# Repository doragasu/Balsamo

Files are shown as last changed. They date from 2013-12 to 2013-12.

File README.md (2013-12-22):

Balsamo
=======

A gadget (HW + SW) for unwanted calls filtering. The name comes from the Spanish acronym "Bloqueador Avanzado de Llamadas Sistemáticas, Automáticas, Molestas y Ocultas", that means something like "Advanced Blocker for Systematic, Automatic, Annoying and Hidden Calls". The acronym itself, means "Balm". When Balsamo detects an incoming call, it decodes the caller number. If the number is configured to be blocked (or if the number is hidden and hidden numbers are configured to be blocked), BALSAMO answers the call with a message pre-recorded inside a microSD card.

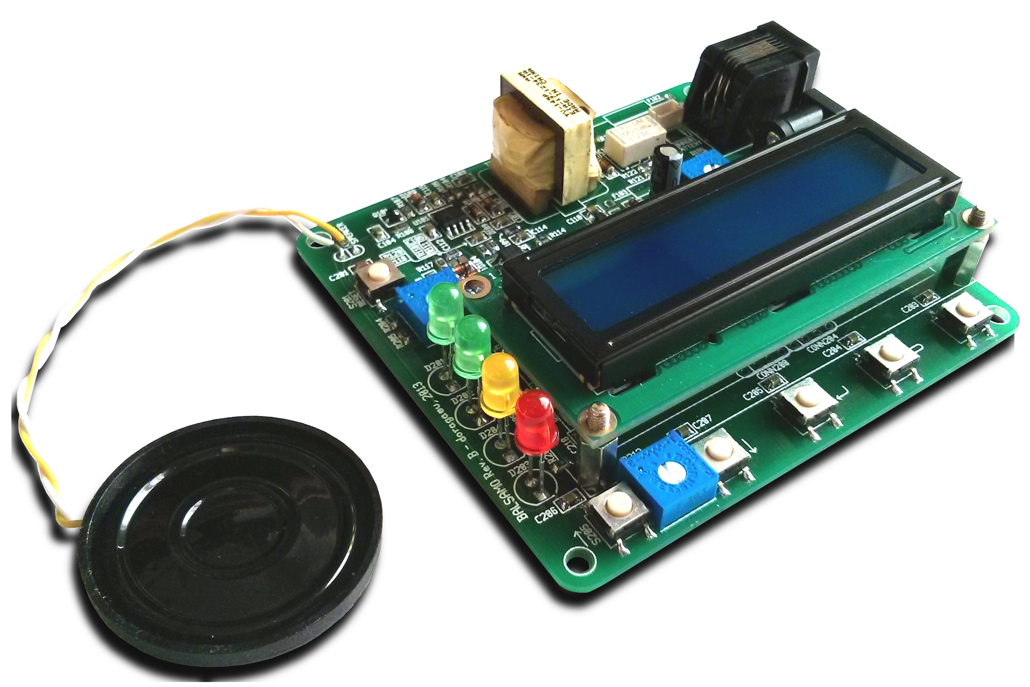
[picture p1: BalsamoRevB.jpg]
Balsamo Rev.B Balsamo Revision B


Features
========
- Caller ID (CID) decoding, to obtain the caller's number.
- Capability to blacklist/whitelist calls, based on caller's number and on wether the caller number is private/hidden.
- Both blacklist (block all numbers inside the list) and whitelist (allow only the numbers inside the list) are supported.
- Private/hidden numbers can also be allowed or rejected.
- Two different audio messages can be played to the caller, each time a call is rejected. One message is for calls blacklisted or not included in the whitelist. The other is for private/hidden calls.
- microSD card slot. The card records the audio message files, the configuration file (including the blacklist/whitelist) and the log file.
- Logs to microSD card all the calls, and the action performed for each of them (ALLOW/BLOCK).
- Simple user interface with a 2x16 LCD, 4 LEDs and 5 pushbuttons (only 4 of them are used so far).
- Very low power design. While idle (most of the time, waiting for an incoming call) most of the system is shut down (almost everything excepting the LCD and RING detector), draining around 4,4 mA. While active, current goes up to around 20 mA.
- Optimized FSK decoder implementation. It has been written mostly in dsPIC assembly language, and carefully optimized.
- Custom PCB with only one chip (a dsPIC) performing most of the actions. No external ADC, DAC, CID decoder, SD controller, Flash memory chip, etc. Only a dsPIC and some analog chips.
- Design allows for a backup battery to be used, for the system to continue operating (and without losing date and time) when the main power source fails.
- Lots of free PADs in the PCB, to allow hacking/expanding the design as needed.
- Everything in this project (source code, schematics, board files and documentation, excepting external libraries used) is GPLv3+ licensed.

External components used
========================

Balsamo uses the following external components:
- [fatfs by Elm-Chan](http://elm-chan.org/fsw/ff/00index_e.html) (unrestricted free license).
- Modified XLCD by Microchip (can be freely used with its microcontrollers).
- Runtime support and chip support files. These files come with [MPLAB C Compiler for PIC24 MCUs and dsPIC DSCs](http://www.microchip.com/stellent/idcplg?IdcService=SS_GET_PAGE&nodeId=1406&dDocName=en010065). Free (as in beer) version of the compiler can be used to build the project. Feel free to add support for other compilers.
- dspcommon.inc and iircan.s from [dsPIC DSC DSP Algorithm Library](http://www.microchip.com/stellent/idcplg?IdcService=SS_GET_PAGE&nodeId=1406&dDocName=en023598). This library is usually also included with "MPLAB C Compiler for PIC24 MCUs and dsPIC DSCs" and can be freely used with dsPIC products from Microchip.
- (Optional) [Doxygen](http://www.stack.nl/~dimitri/doxygen/) if you want to build the documentation yourself.

Editing Schematics and PCB
==========================

Schematics and PCB files can be found under `sch/rev-B` directory.

Schematics have been created using [gschem](http://www.gpleda.org/) 1.8.1. Note you will need to properly install and configure it, including the free symbols I have created. You can find them in my [doragasu-gpleda-lib](https://github.com/doragasu/doragasu-gpleda-lib) GitHub repository.

PCB has been routed using [PCB](http://pcb.geda-project.org) version 1.99z and it's built-in (and buggy!) toporouter. To create the teardrops in the pin to track connections, you will need the [Teardrops Plug-in by DJ Delorie](http://www.delorie.com/pcb/teardrops/). Because you cannot easily undo teardrops once created (or at least I do not know how), there are two PCB designs included in the project: `Balsamo.pcb` and `Balsamo-tear.pcb`. `Balsamo-tear.pcb` is the final PCB (and is the one used to generate the GERBER files). `Balsamo.pcb` is the same as `Balsamo-tear.pcb`, but without the teardrops. If you need to edit the PCB, `Balsamo.pcb` is the one you should use.

It's recommended to install xgsch2pcb to open the Balsamo.gsch2pcb file and easily access the schematics, the PCB and the netlist creation tool. There are also two scripts (`bom` and `drc-check`) to create a bill of materials and to check design rules.

Building the firmware
=====================

As previously stated, [MPLAB C Compiler for PIC24 MCUs and dsPIC DSCs](http://www.microchip.com/stellent/idcplg?IdcService=SS_GET_PAGE&nodeId=1406&dDocName=en010065) has been used to build the firmware. The compiler homepage offers a 60 day fully working trial version. After this trial, most compiler optimizations are disabled, but it should be able to generate an unoptimized but working firmware image. I have not yet tried building the firmware using the [gnu-based academic version of the compiler](http://www.microchip.com/stellent/idcplg?IdcService=SS_GET_PAGE&nodeId=1406&dDocName=en536656), but it may be worth a try.

Configuration file format
=========================

Balsamo uses a configuration file called `BALSAMO.CFG`, that must be placed in the root of a FAT formatted (both FAT16 and FAT32 should work) microSD card. `BALSAMO.CFG` format is as follows:
- First line must be either `BLACKLIST` if you want all the numbers in the file to be blocked, or `WHITELIST` if you want to block all the numbers excepting the ones in the list.
- Second line must be either `BLACKLIST_UNKNOWN` if you want all the private/hidden calls to be rejected, or `ALLOW_UNKNOWN` if you want to allow private/hidden calls.
- Lines 3 and beyond contain the list of numbers to be blacklisted/whitelisted (depending on the mode set in line 1). Only one number per line is allowed.

An example `BALSAMO.CFG` file that will blacklist numbers 555555555, 123456789 and 987654321, and will allow private/hidden calls, is as follows:

    BLACKLIST
    ALLOW_UNKNOWN
    555555555
    123456789
    987654321

Creating RAW audio files for BALSAMO
====================================

A GNU Octave/Matlab script called wav2raw is provided under `src/wav2raw`, to convert 8 kHz MONO wav files to the RAW format used by BALSAMO. The `src/wav2raw/README.md` file has additional details about how to use this script to generate the RAW audio files.

Two audio files can be used with Balsamo. They must be placed in the root of the microSD card:
- `FILTER.RAW`: This file is played each time a call is rejected due to number in blacklist or not in whitelist.
- `FORBID.RAW`: This file is played each time a call is rejected because the number is private/hidden, and these kind of calls are configured to be blocked (`BLACKLIST_UNKNOWN` is set in the second line of the `BALSAMO.CFG` file).

LOG file format
===============

Balsamo stores a log file inside the root of the SD card, called `BALSAMO.LOG`. Each line of this file corresponds to a call event, starting with date and time, following with the caller number (if any) and ending with the action performed by Balsamo and an optional comment. An example section of a Balsamo log file looks like this:

        15/11/2013, 09:51 --> 123456789 ALLOWED
        15/11/2013, 10:16 --> 555555555 BLOCKED
        15/11/2013, 18:35 --> PRIVATE BLOCKED
        15/11/2013, 20:21 --> 555555555 ALLOWED, FILTER DISABLED!
        15/11/2013, 20:32 --> PRIVATE ALLOWED, FILTER DISABLED!

Built-in amplifier
==================

Rev.B of the Balsamo PCB features a small amplifier, able to drive a little speaker. This amplifier has been tested and works, but it is unused at the moment. It might be used in the future to play a notification sound when a call is blocked, and to play previously recorded calls (if I implement the answering machine capabilities). If you are brave enough to try building your own Balsamo, you don't need to assemble the amplifier to get all the functionalities implemented right now.

Some features I might add
============================================================

Some things I'd like to add (if I get the time and motivation):

- Call recording support. Recording should be relatively easy using the free [dsPIC DSC Speex Speech Encoding/Decoding Library](http://www.microchip.com/stellent/idcplg?IdcService=SS_GET_PAGE&nodeId=1406&dDocName=en023610), but I have to figure out a way to guess when the caller has hung.
- Answering machine functionalities. Should also be very easy once voice recording is implemented. It will use the audio amplifier included in Rev.B PCB (already tested and working).
- Different audio message playing depending on caller number.
- Use PWM to drive LCD backlight, so the variable resistor used to set backlight intensity can be removed.

Enjoy!

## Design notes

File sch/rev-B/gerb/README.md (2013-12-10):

Here you can find GERBER files for sending to a fab house. Most file names are self-explanatory. Note there is no bottom silkscreen. Balsamo.gvp file is not needed, but I leave it here because it's handy for loading the GERBER files using *Gerbv Gerber File Viewer*.

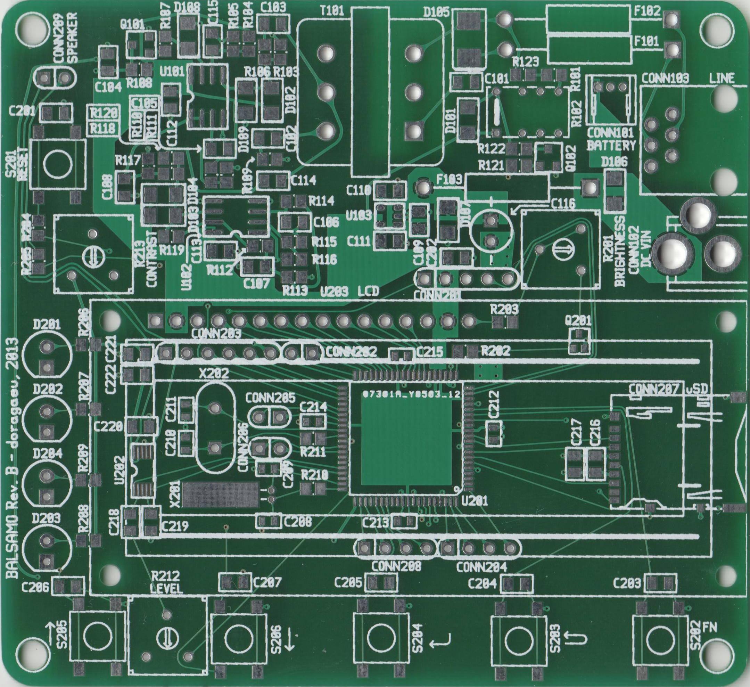
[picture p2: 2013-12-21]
doc/BalsamoRevB-TOP.jpg

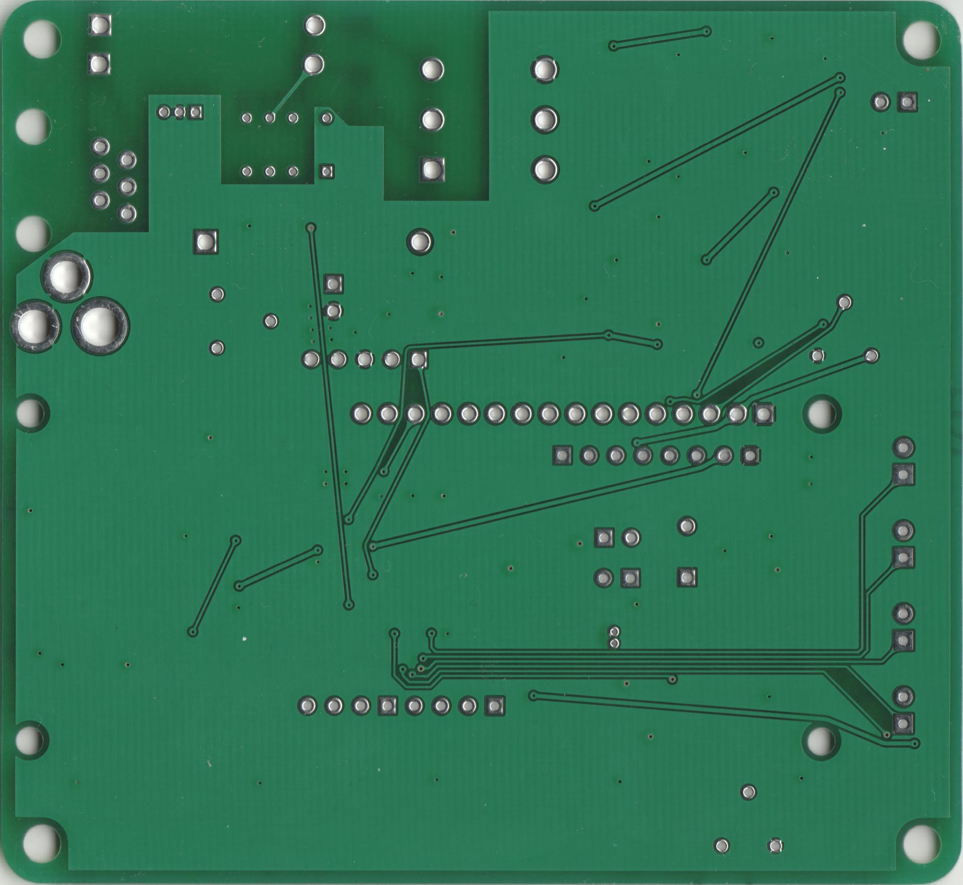
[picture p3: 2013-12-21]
doc/BalsamoRevB-BOT.jpg

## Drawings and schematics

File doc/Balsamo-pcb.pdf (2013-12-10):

# /home/jalon/Documentos/Electr/Balsamo/sch/Balsamo-tear.pcb

# 1. Table of Contents (This Page) Created on Tue Dec 10 15:05:14 2013

# 2. top 3. bot 4. outline 5. plated-drill 6. unplated-drill 7. componentmask 8. soldermask 9. topsilk 10. bottomsilk 11. toppaste 12. topassembly 13. bottomassembly 14. fab

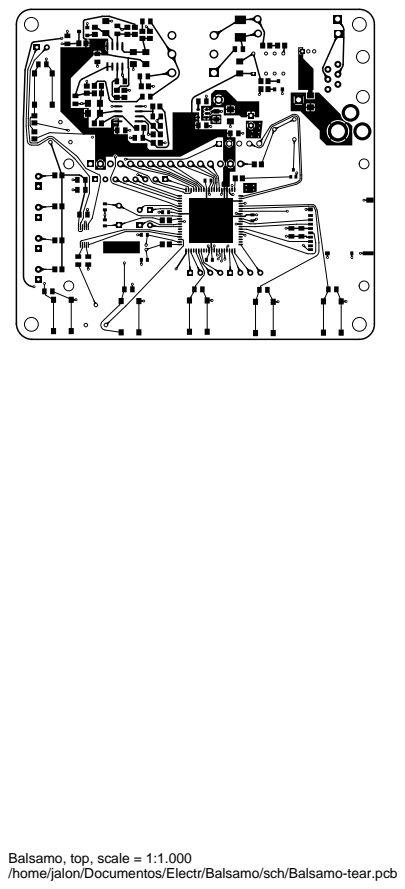
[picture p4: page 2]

Balsamo, top, scale = 1:1.000

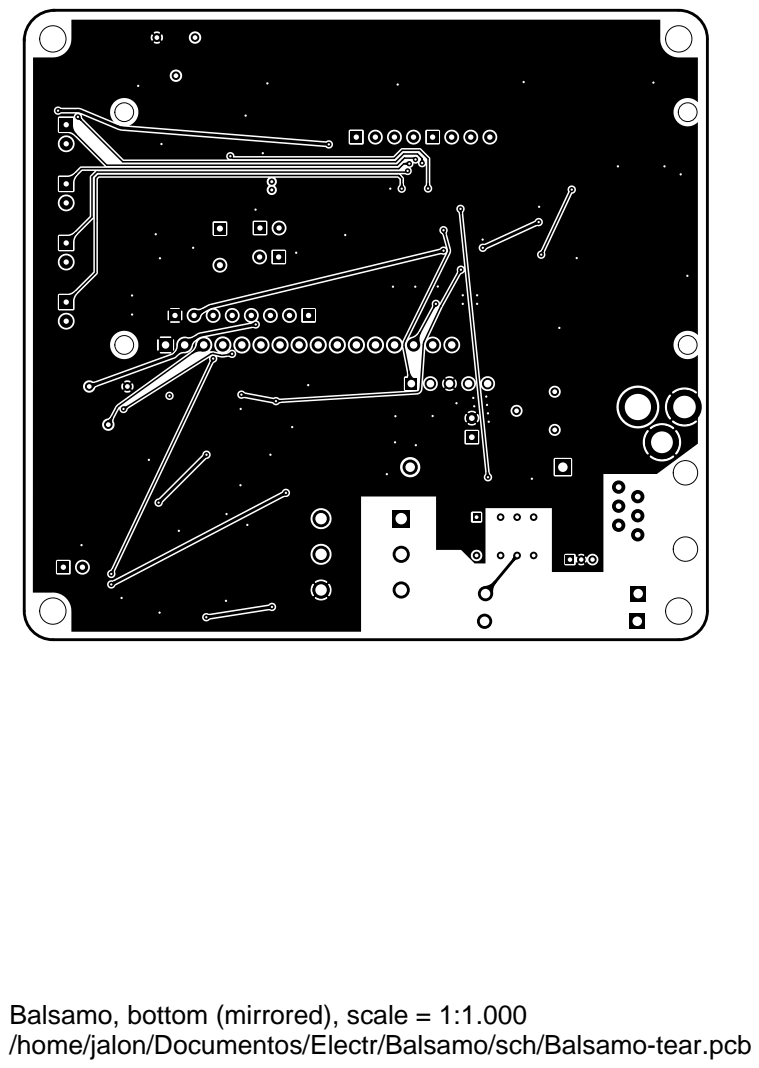
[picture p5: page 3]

Balsamo, bottom (mirrored), scale = 1:1.000

Balsamo, outline, scale = 1:1.000

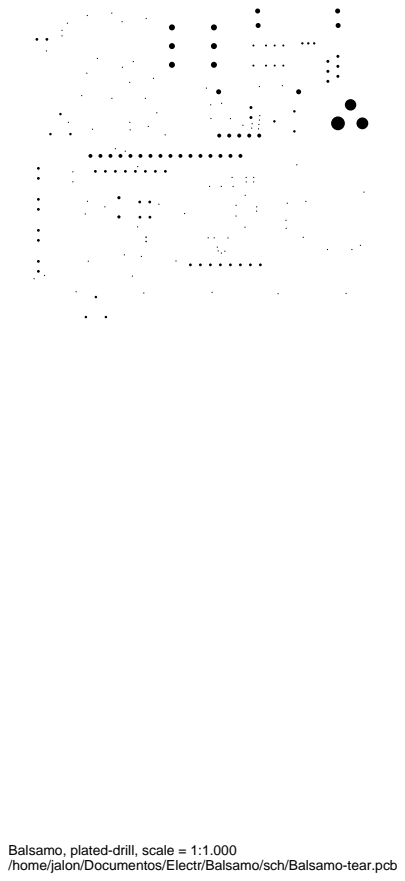
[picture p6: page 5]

Balsamo, plated-drill, scale = 1:1.000

Balsamo, unplated-drill, scale = 1:1.000

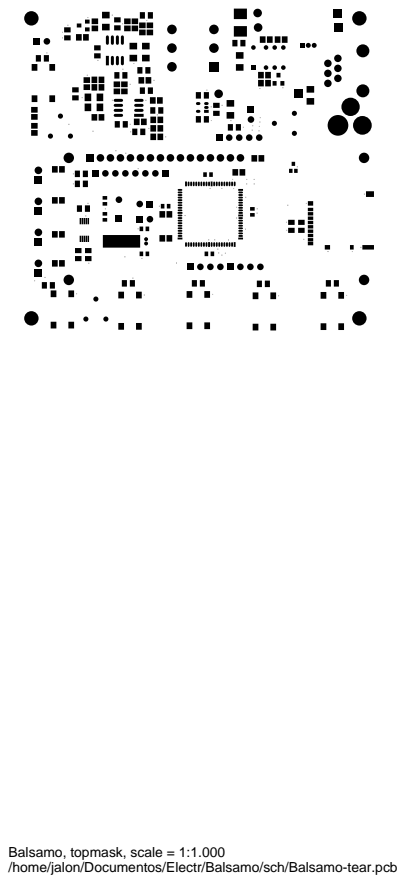
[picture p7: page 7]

Balsamo, topmask, scale = 1:1.000

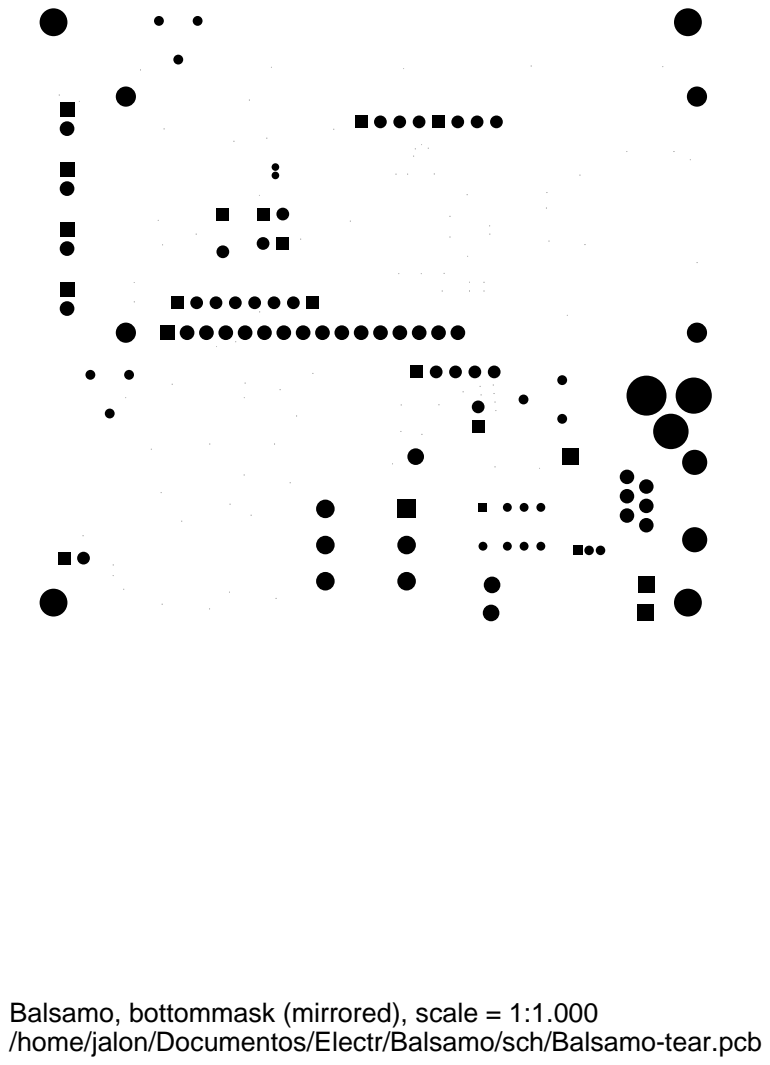
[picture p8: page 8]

Balsamo, bottommask (mirrored), scale = 1:1.000

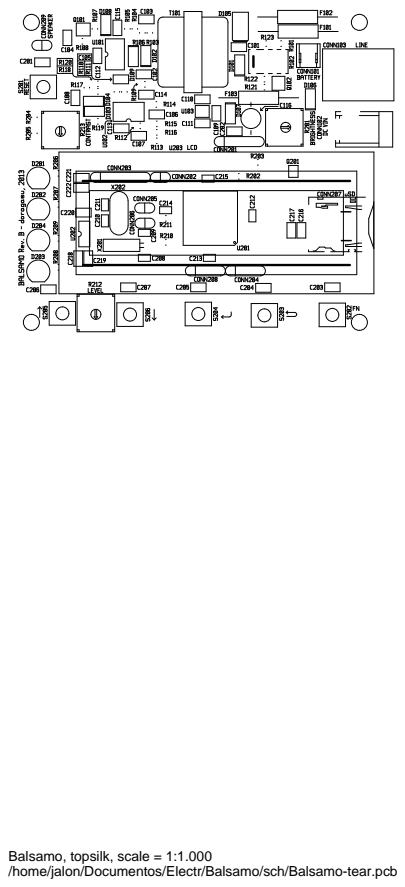
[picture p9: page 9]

Balsamo, topsilk, scale = 1:1.000

Balsamo, bottomsilk (mirrored), scale = 1:1.000

Balsamo, toppaste, scale = 1:1.000

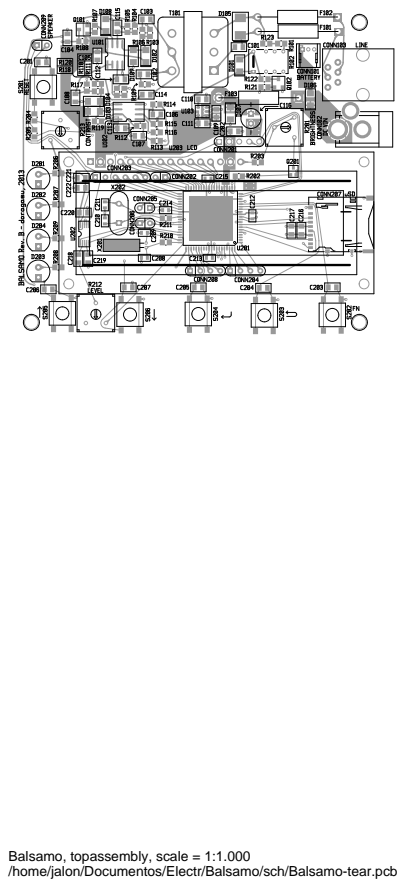
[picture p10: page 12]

Balsamo, topassembly, scale = 1:1.000

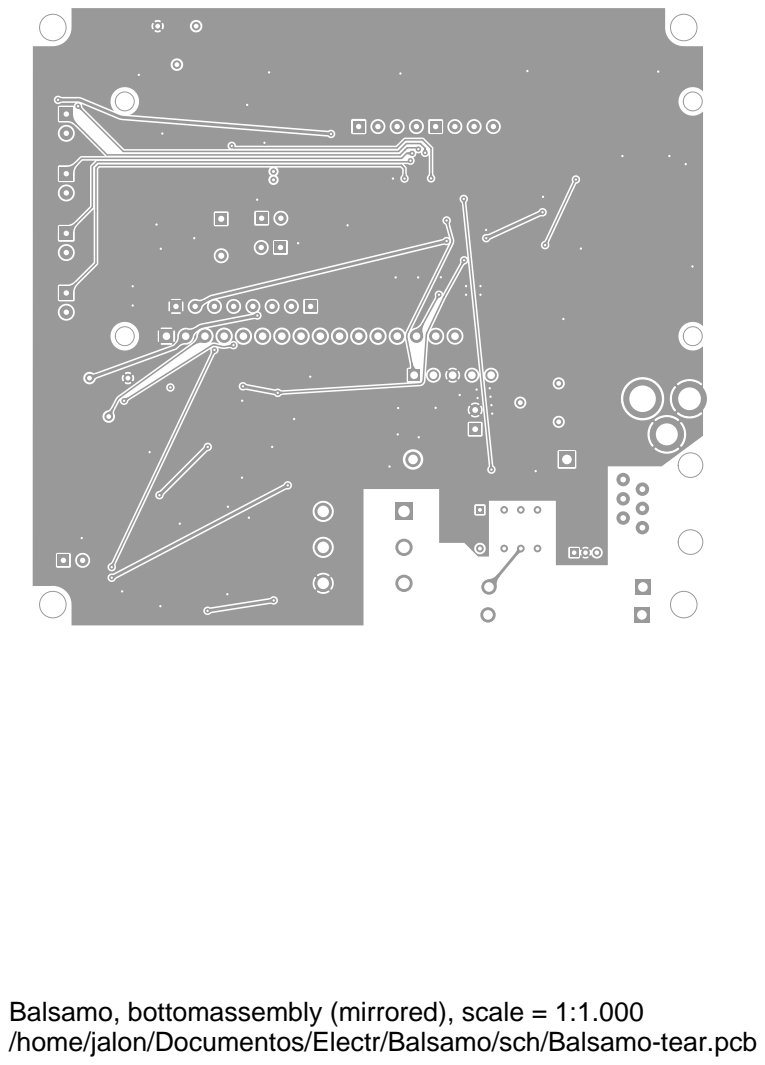
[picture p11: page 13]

Balsamo, bottomassembly (mirrored), scale = 1:1.000

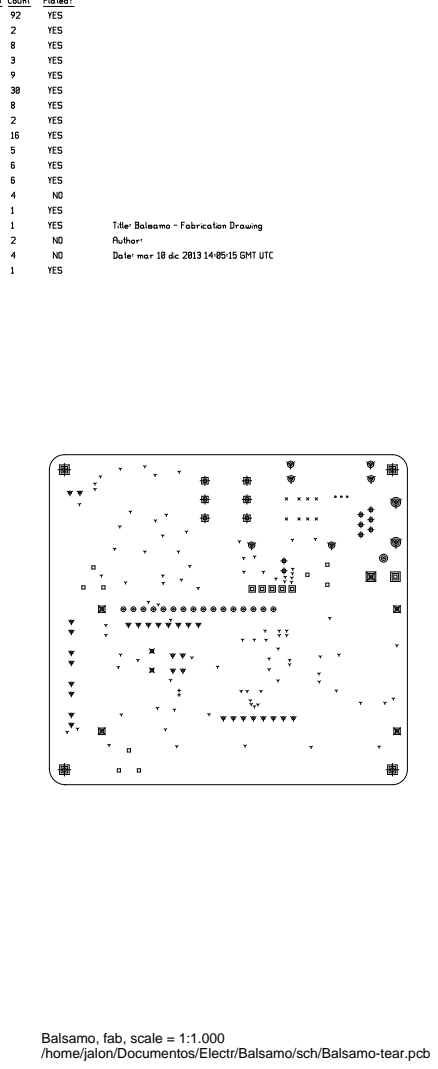
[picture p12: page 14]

Balsamo, fab, scale = 1:1.000

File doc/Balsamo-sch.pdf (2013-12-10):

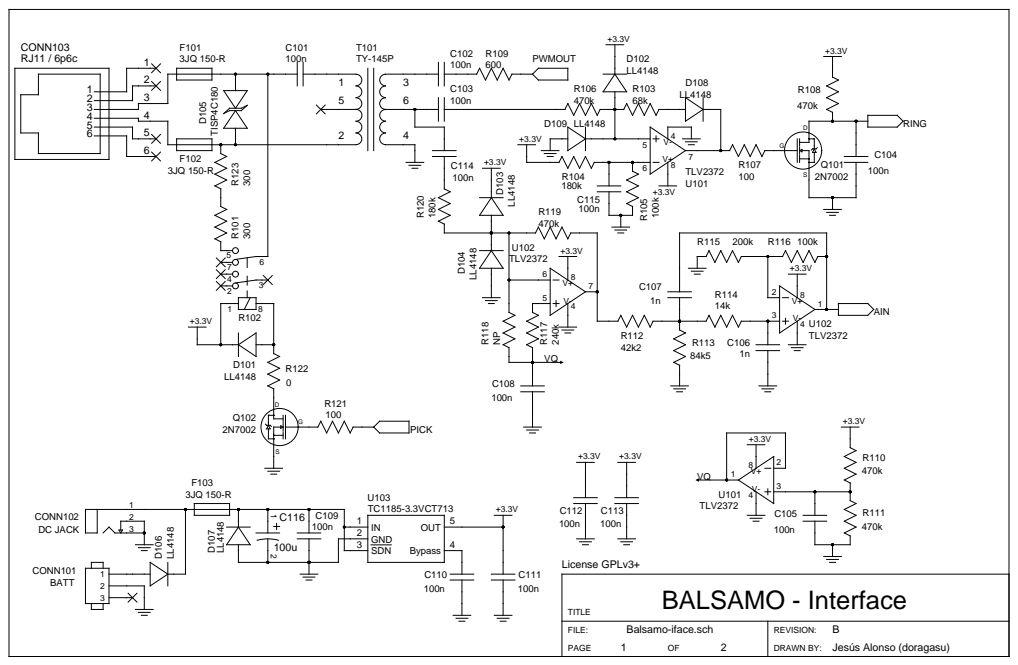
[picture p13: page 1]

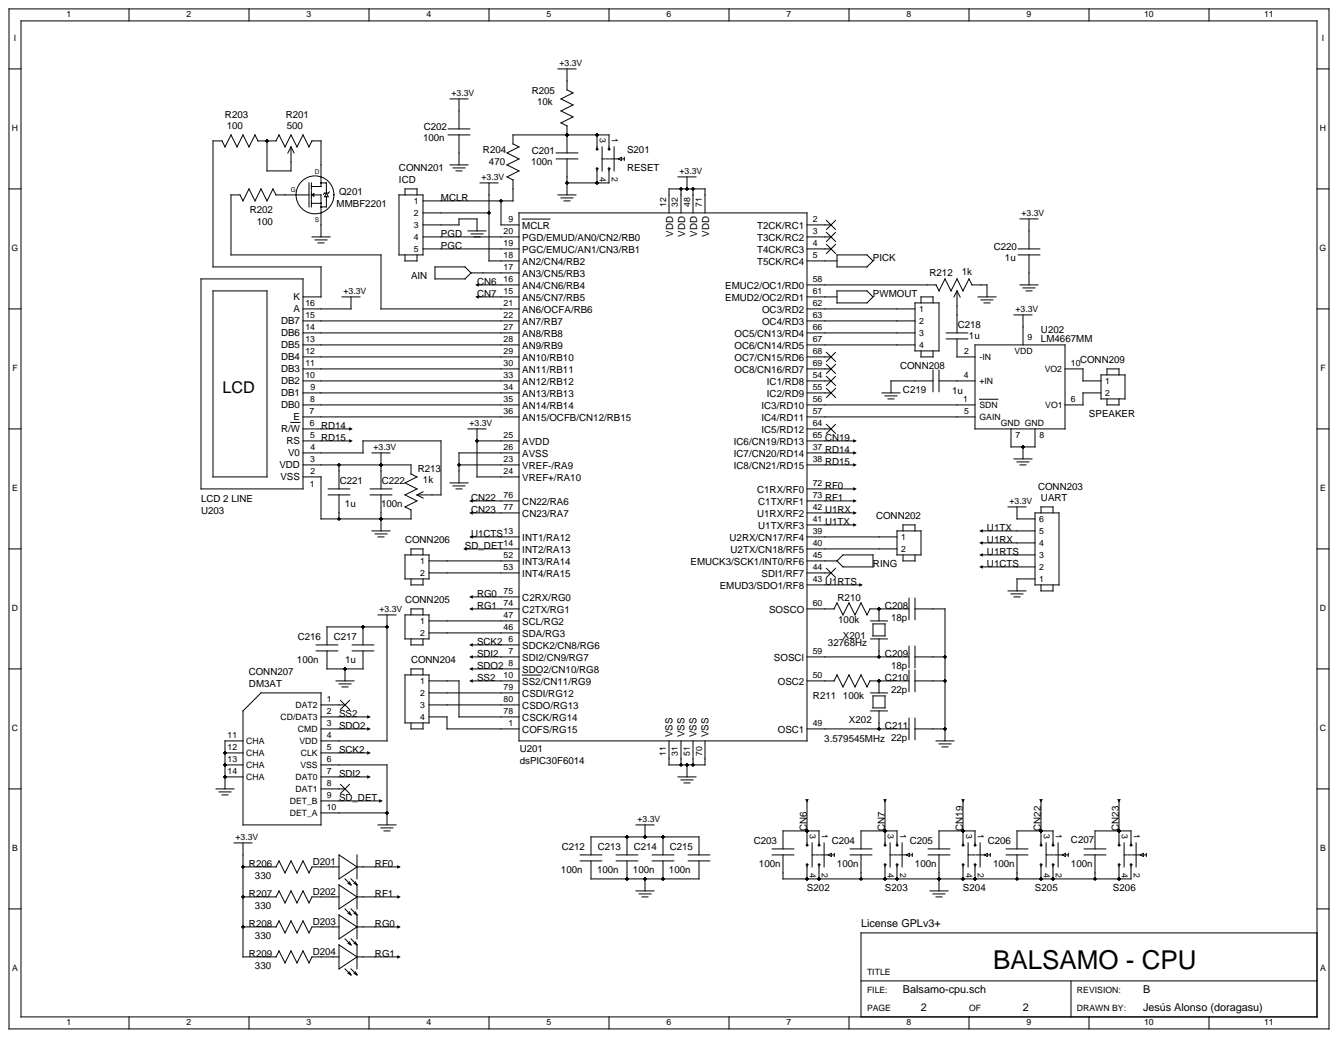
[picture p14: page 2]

PGD | PGD/EMUD/AN0/CN2/RB0 20 | 3
PGC | PGC/EMUC/AN1/CN3/RB1 19 | 4

AN10/RB10 29 | | VDD SDN GND GND | 10 VO2
AN11/RB11 30 | CONN208

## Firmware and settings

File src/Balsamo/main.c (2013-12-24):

/************************************************************************//**
 * \file main.c
 * \brief BALSAMO: Bloqueador Avanzado de Llamadas Sistemáticas, Automáticas,
 * Molestas y Ocultas.
 *
 * This project allows to block and automatically answer incoming calls.
 * Calls can be filtered using either a blacklist or a whitelist with
 * telephone number. Also unidentified callers can be either allowed or
 * blocked. An acoustic message can be played to filtered calls, and other
 * different message can be used for unallowed unidentified callers.
 *
 * \author Jesus Alonso Fernandez (doragasu)
 * \date 2013
 * \todo Add a way to unmount SD card
 * \license GPL-3.0+ <http://www.gnu.org/licenses/gpl.html>
 *****************************************************************************/
/* This file is part of BALSAMO source package.
 *
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
 * You should have received a copy of the GNU General Public License
 * along with BALSAMO.  If not, see <http://www.gnu.org/licenses/>.
 */

#include "common.h"
#include <p30F6014.h>
#include <string.h>
#include "system.h"
#include "line_if.h"
#include "cid.h"
#include "leds.h"
#include "keyb.h"
#include "adc.h"
#include "user_if.h"
#include "ext_uart.h"
#include "tim_evt.h"
#include "fsk_dem.h"
#include "rtc.h"
#include "fatfs/ff.h"
#include "fatfs/diskio.h"
#include "rtc.h"
#include "tel_filt.h"
#include "utils.h"
#include "rawplay/rawplay.h"

// Uncomment to output debug messages to the serial port
//#define _DEBUG
/// Timeout in seconds for receiving CID data since the first RING pattern
#define TIM_TOUT		5
/// Timeout in seconds between RING patterns
#define RING_WAIT_TIM	5
/// Sleep timeout in seconds, mostly used to keep ON the backlight some
/// seconds, and ensure data gets flushed to the SD card.
#define SLEEP_TOUT		5

/// Timer number used for system events (for tim_evt module)
#define SYS_EVT_TIM		0
/// Timer used for the sleep timer (for tim_evt module)
#define SLEEP_EVT_TIM	1

/// Filename of the message to be played for filtered calls
#define FILE_MSG_FILTERED		"FILTER.RAW"
/// Filename of the message to be played for forbidden unidentified calls
#define FILE_MSG_FORBIDDEN		"FORBID.RAW"

/// Puts a character in the UART
#define Put(char)			\
{ 							\
	while(U1STAbits.UTXBF); \
	U1TXREG = (char);		\
}

/// Converts a two byte ascii number to decimal
#define A2Dec(upper, lower)	(((upper)-'0')*10+((lower)-'0'))

// Private prototypes
void SysInit(void);
void CallProcEnd(void);
void TimEvtWait(unsigned int countMs);
char ParseMessages(void);
void FatFsHwInit(void);
void SysFsm(void);
void Log(char str[]);
void LogNumStr(char num[], char str[]);

/// Line 1 of the welcome message
static const char line1[] = "BALSAMO HW Rev.B";
/// Line 2 of the welcome message
static const char line2[] = "BALSAMO FW v1.0 ";
/// Buffer used to temporary store the received telephone number line
static char telNum[17];

/// When going to LPM, if sleep is TRUE, system will Sleep.
/// If false, system will Idle instead.
static char sleep = TRUE;
/// FatFs status
static BYTE fatFsStat;
/// FatFs volume
static FATFS vol;
/// Log file
static FIL fLog;
/// If TRUE, events will be logged to BALSAMO.LOG file
static char evLog;
/// System status
SysStat  sysStat  = SYS_SLEEP;
/// Last occured system event
SysEvent sysEvent;

/// Main function. It just initializes system, and then Sleeps/Idles most of
/// the time. When awake, it just loops on the system state machine SysFsm().
int main(void)
{
	/// Initialize system
	SysInit();

	/// System loop
	while(TRUE)
	{
		///- Get an event from the system queue.
		sysEvent = SysQueueGet();
		switch (sysEvent)
		{
			///- If no event to process, Sleep/Idle again
			case SYS_NONE:
				// Nothing to do, just Sleep or Idle depending on status
				if (sleep) {Sleep();}
				else Idle();
				break;

			///- If a SLEEP event is received, go to Sleep mode
			case SYS_SLEEP_TIM:
				// Power backlight OFF and go to Sleep mode
				BacklightOff();
				// Wait until TMR1 != 0 (see 12.12.1 in the datasheet)
				while (!TMR1);
				sleep = TRUE;
				Sleep();
				break;

			///- Any other event must be handled by the system state machine
			default:
				SysFsm();
		} // switch
	} // while(TRUE)
} // main

/************************************************************************//**
 * System state machine. Processes incoming events and executes actions
 * depending on the system status and the received event.
 ****************************************************************************/
void SysFsm(void)
{
	/// ADC raw data buffer
	fractional* dataBuf;
	/// Demodulated bytes buffer
	BYTE recvBuf[NS/FSK_SPB/10 + 1];
	/// Handles return codes
	static BYTE reason = 0;
	/// Lenght of the received packet
	int recvLen;
#ifdef _DEBUG
	/// Used for some debug loops
	int i;
#endif

	// Process the event depending on the system status
	switch(sysStat)
	{
		case SYS_SLEEP:
			switch(sysEvent)
			{
				case SYS_RING:
					// Disable sleep. We will idle instead because
					// we need the timer clock to be enabled
					TimEvtStop(SLEEP_EVT_TIM);
					sleep = FALSE;
					// RING received, launch 500 ms wait timer
					TimEvtRun(SYS_EVT_TIM, 500);
					// Turn backlight ON
					BacklightOn();

					// Turn ON the RING LED
					SetD201(LED_ON);
					// Switch to the ring timer wait status
					sysStat = SYS_RING_TIM;
					/// Pass event to user interface
					UifEventParse(SYS_RING, NULL, 0);
					break;

				case SYS_KEY_UP:
				case SYS_KEY_DOWN:
				case SYS_KEY_ENTER:
				case SYS_KEY_ESC:
				case SYS_KEY_FN:
					// Key events temporary turn ON backlight and are handled
					// by the user interface state machine UifEventParse()
					BacklightOn();
					UifEventParse(sysEvent, NULL, 0);
					sleep = FALSE;
					TimEvtRun(SLEEP_EVT_TIM, SLEEP_TOUT * 1000);
					break;

				case SYS_RTC_MINUTE:
					// Call UI FSM to refresh date and time count
					UifEventParse(sysEvent, NULL, 0);
				default:
					break;
			}// switch(sysEvent)
			break;

		case SYS_RING_TIM:
			switch(sysEvent)
			{
				case SYS_TIM_EVT:
					// Completed 500 ms wait.
					// D202 will blink when receiving ADC data
					SetD202(LED_ON);
					// Launch FSK pattern timeout
					TimEvtRun(SYS_EVT_TIM, TIM_TOUT * 1000);
					// Start ADC
					AdcStart();
					// Switch to ADC data receive status
					sysStat = SYS_DATA_RECV;
					break;
				default:
					break;
			}// switch(sysEvent)
			break;

		case SYS_DATA_RECV:
			switch(sysEvent)
			{
				case SYS_DATA:
					// Blink D202
					ToggleD202();
					// Get and demodulate received audio data
					dataBuf = AdcGetBuf();
					recvLen = FskDemod(dataBuf, recvBuf);
#ifdef _DEBUG
					for (i = 0; i < recvLen; i++) Put(recvBuf[i]);
#endif
					// Handle demodulated data to the CID decoder
					if (recvLen)
					{
						switch(CidParse(recvBuf, recvLen))
						{
							case CID_OK:
								// OK, but still not finished, continue
								break;

							case CID_ERROR:
								// Error, end call process and idle
								TimEvtRun(SYS_EVT_TIM, RING_WAIT_TIM * 1000);
								sysStat = SYS_RING_END_WAIT;
								AdcStop();
								Log("CID ERROR!");
								// Inform UIF module
								UifEventParse(SYS_CALL_NOT_SENT, NULL, 0);
								break;

							case CID_END:
								// CID finished. Parse received messages
								switch (reason = ParseMessages())
								{
									// Accept hidden call
									case TF_HID_OK:
									// Accept number
									case TF_NUM_OK:
										LogNumStr(telNum, "ALLOWED");
										UifEventParse(SYS_CALL_ALLOWED,
											telNum, 16);
										sysStat = SYS_RING_END_WAIT;
										TimEvtRun(SYS_EVT_TIM, RING_WAIT_TIM *
												  1000);
										break;
									// Reject call because of black/whitelist
									case TF_NUM_REJECT:
									// Reject call because of private/unknown
									case TF_HID_REJECT:
										// Pick up
										LinePickUp();
										SetD204(LED_ON);
										sysStat = SYS_LINE_HANG_WAIT;
										/// \todo Play message from SD card
										AdcStop();
										TimEvtRun(SYS_EVT_TIM, 3 * 1000);
										LogNumStr(telNum, "BLOCKED");
										/// \todo Send message to user_if
										UifEventParse(SYS_CALL_RESTRICTED,
											telNum, 16);
										break;
									// Accept number because filter disabled
									case TF_FILTER_DISABLED:
									// Accept hidden call because
									// filter disabled
									case TF_HID_DISABLED:
										LogNumStr(telNum,
											"ALLOWED, FILTER DISABLED!");
										UifEventParse(SYS_CALL_ALLOWED,
											telNum, 16);
										sysStat = SYS_RING_END_WAIT;
										TimEvtRun(SYS_EVT_TIM, RING_WAIT_TIM *
												  1000);
										break;
								} // switch(ParseMessages())
								break;
						} // switch(CidParse(recvBuf, recvLen))
					} // if (recvLen)
					break;

				case SYS_TIM_EVT:
					// Timeout for FSK data
				case SYS_RING:
					// Another ring pattern received, so the FSK data was
					// not sent, or we missed it, end call and idle/sleep
					TimEvtRun(SYS_EVT_TIM, RING_WAIT_TIM * 1000);
					sysStat = SYS_RING_END_WAIT;
					AdcStop();
					Log("NOT SENT!");
					// Inform UIF module
					UifEventParse(SYS_CALL_NOT_SENT, NULL, 0);
					break;
				default:
					break;
			}// switch(sysEvent)
			break;

		case SYS_RING_END_WAIT:
			// Wait until we stop receiving ring patterns,
			// and go back to sleep
			switch (sysEvent)
			{
				case SYS_RING:
					// Reset the ring timer
					TimEvtRun(SYS_EVT_TIM, RING_WAIT_TIM * 1000);
					break;

				case SYS_TIM_EVT:
					// We finished receiving RINGs, end call process
					CallProcEnd();
					break;
				default:
					break;
			}
			break;

		case SYS_LINE_HANG_WAIT:
			if (sysEvent == SYS_TIM_EVT)
			{
				// Play message and end call
				RawPlayFile(reason == 1?FILE_MSG_FILTERED:FILE_MSG_FORBIDDEN);
				LineHang();
				CallProcEnd();
			}
			break;
		default:
			// We should never reach here
			break;
	}// switch(sysStat)
}

/// \brief Parses CID messages.
/// \return TF_OK, TF_NUM_REJECT, TF_DISABLED, TF_HID_REJECT, TF_HID_OK or
/// TF_HID_DISABLED as in tel_filt.h.
char ParseMessages(void)
{
	/// Received message
	char *msg;
	/// Loop control variable
	int i;
	/// Received message length
	int msgLen;
	/// Decoded message code
	unsigned char msgCode;
	/// Used for error handling
	unsigned char lastErr = 0;
	/// Used to obtain function return values
	char retVal = TF_NUM_OK;

	/// Clear telephone number
	for (i = 0; i < 16; i++) telNum[i] = ' ';
	telNum[16] = '\0';

	/// Analyse received message code
	while ((msgCode = CidPlMsgParse(&msgLen, &msg)))
	{
		switch(msgCode)
		{
			case CID_MSG_DATE_TIME:
				/// Obtain date and time
				if (msgLen == 8)
				{
					/// Set the time
					RtcSetTime(A2Dec(msg[0], msg[1]),
						A2Dec(msg[2], msg[3]), A2Dec(msg[4], msg[5]),
						A2Dec(msg[6], msg[7]), 0);
				}
				else lastErr = msgCode;
				break;

			case CID_MSG_CLI_A:
			case CID_MSG_CLI_B:
				/// Obtain telephone number
				if (msgLen <= CID_TELNUM_MAX_LEN)
				{
					for (i = 0; (i < msgLen) && (i < 16); i++)
						telNum[i] = msg[i];
					telNum[i] = '\0';
					retVal = TfNumCheck(telNum);
				} else lastErr = msgCode;
				break;

			case CID_MSG_CLI_ABS_REASON:
				/// Obtain reason for telephone number absence
				if (msgLen == CID_CLI_ABS_REASON_LEN)
				{
					retVal = TfFilterHidden();
					switch(*msg)
					{
						case CID_ABS_UNAVAILABLE:
							strcpy(telNum, "UNAVAILABLE");
							break;

						case CID_ABS_PRIVATE:
							strcpy(telNum, "PRIVATE");
							break;

						default:
							strcpy(telNum, "UNKNOWN");
							break;
					}
				}
				else lastErr = msgCode;
				break;
			case CID_MSG_CP_NAME:
				// Ignored right now
				/// \todo Implement message parsing
			default:
				lastErr = msgCode;
				break;
		} // switch();
	} // while();
	return retVal;
}

/// System initialization
void SysInit(void)
{
	FRESULT retVal;

	/// Timer initialization
	TimEvtInit();
	TimEvtConfig(SYS_EVT_TIM, SYS_TIM_EVT);
	TimEvtConfig(SLEEP_EVT_TIM, SYS_SLEEP_TIM);

	/// Start RTC
	RtcStart();

	/// Initialize 2x16 LCD
#ifndef EIGHT_BIT_INTERFACE
	OpenXLCD(FOUR_BIT & TWO_LINE & SEG1_50_SEG51_100 & COM1_COM16);
#else
	OpenXLCD(EIGHT_BIT & TWO_LINE & SEG1_50_SEG51_100 & COM1_COM16);
#endif

	/// Initialize LEDs and make them blink once
	LedInit();
	SetD13(LED_ON);
	TimEvtWait(250);
	SetD13(LED_OFF);
	SetD14(LED_ON);
	TimEvtWait(250);
	SetD14(LED_OFF);
	SetD16(LED_ON);
	TimEvtWait(250);
	SetD16(LED_OFF);
	SetD15(LED_ON);
	TimEvtWait(250);
	SetD15(LED_OFF);

	BacklightOn();
	XLCD_BUSY_WAIT();
	WriteCmdXLCD(DON & CURSOR_OFF & BLINK_OFF);
	/// Write hardware and firmware version
	XLCD_PUTS(line1);
	XLCD_LINE2();
	XLCD_PUTS(line2);
	TimEvtWait(2000);
	BacklightOff();

	/// Configure UART1 for debug stdout/stdin
#ifdef _DEBUG
	ExtUart1Init();
	ExtUart1Enable();
#endif

	/// Initialise FatFs
	FatFsHwInit();
	fatFsStat = disk_initialize(0);
	if (!fatFsStat) fatFsStat = f_mount(0, &vol);
	if (fatFsStat)
	{
		XLCD_CLEAR();
		XLCD_PUTS("SD CARD DAMAGED");
		XLCD_LINE2();
		XLCD_PUTS("OR NOT INSERTED!");
		PANIC();
	}
	/// Parse configuration file in SD Card
	if (TfParseConfig())
	{
		XLCD_CLEAR();
		XLCD_PUTS("BALSAMO.CFG FILE");
		XLCD_LINE2();
		XLCD_PUTS("NOT VALID/FOUND!");
		PANIC();
	}

	/// Open log file and place cursor at its end.
	/// \warning If log file opening fails, the system will not warn user.
	retVal = f_open(&fLog, "BALSAMO.LOG", FA_READ | FA_WRITE | FA_OPEN_ALWAYS);
	if (!retVal) retVal = f_lseek(&fLog, f_size(&fLog));
	evLog = !retVal;

	/// User interface initialization
	UifInit();
	/// Demodulation and CID interpreter initialization
	FskDemodInit();
	CidReset();
	// ADC initialization
	AdcInit();
	/// Telephone line interface initialization
	LineInit();
	LineRingDetEnable();

	/// Keypad initialization
	KeybInit();
	KeybIntsEnable();

	/// PWM player module initialization
	RawPlayInit();
}

/// End call process. Stops ADC, resets FSK demodulator and CID decoder, and
/// launches the Sleep timer.
void CallProcEnd(void)
{
	TimEvtStop(SYS_EVT_TIM);
	AdcStop();
	FskReset();
	CidReset();
	SetD13(LED_OFF);
	SetD14(LED_OFF);
	SetD15(LED_OFF);
	SetD16(LED_OFF);
	TimEvtWait(5000);
	UifEventParse(SYS_CALL_END, NULL, 0);
	sysStat = SYS_SLEEP;
	TimEvtRun(SLEEP_EVT_TIM, SLEEP_TOUT * 1000);
}

/// Waits until TIMER4 reaches a specified count value
/// \param[in] countMs Number of milliseconds to wait
void TimEvtWait(unsigned int countMs)
{
	TimEvtRun(SYS_EVT_TIM, countMs);

	do
	{
		Idle();
	} while(SysQueueGet() != SYS_TIM_EVT);
}

/// Initialises the hardware needed to drive the SD Card using FatFs library
void FatFsHwInit(void)
{
	// Set outputs for SCK2, SDO2 and SS2
	LATG  |=   BIT6 | BIT8 | BIT9;
	TRISG &= ~(BIT6 | BIT8 | BIT9);
	/// Enable internal pullup for SDI2 (CN9)
	CNPU1 |= BIT9;
}

/************************************************************************//**
 * \brief Logs a string to log file, preceded by the date and time.
 *
 * \param[in] str String to log along with num.
 ****************************************************************************/
void Log(char str[])
{
	WORD y;
	BYTE mo, d, h, mi, s;

	_DI();
	RtcGetDate(&y, &mo, &d);
	RtcGetTime(&h, &mi, &s);

	f_printf(&fLog, "%02d/%02d/%d, %02d:%02d --> %s\n", d, mo, y, h, mi, str);
	f_sync(&fLog);
}

/************************************************************************//**
 * \brief Logs a number and an action, preceded by date and time.
 *
 * \param[in] num String containing the number to log.
 * \param[in] str String to log along with num.
 ****************************************************************************/
void LogNumStr(char num[], char str[])
{
	WORD y;
	BYTE mo, d, h, mi, s;

	_DI();
	RtcGetDate(&y, &mo, &d);
	RtcGetTime(&h, &mi, &s);

	f_printf(&fLog, "%02d/%02d/%d, %02d:%02d --> %s %s\n", d, mo, y, h, mi,
			 num, str);
	f_sync(&fLog);	
}

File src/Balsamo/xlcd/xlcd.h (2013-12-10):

/********************************************************************/
/*            Header for XLCD module library functions for          */
/*            P-tec PCOG1602B LCD controller                        */
/*------------------------------------------------------------------*/
/* Modificado por Jesús Alonso para su uso con la placa BALSAMO 1.0 */
/* y el display NHD-0216HZ-FSW-FBW-3V3C basado en el controlador    */
/* SPLC780D. Adapted for Rev.B of BALSAMO PCB.                      */
/********************************************************************/

#if defined(__dsPIC30F__)
#include <p30fxxxx.h>
#elif defined(__dsPIC33F__)
#include <p33Fxxxx.h>
#elif defined(__PIC24H__)
#include <p24Hxxxx.h>
#endif

#if defined(_RD10)

#ifndef _XLCD_H
#define _XLCD_H

/* Comment out the following line if 4-bit interface is being used */
#define EIGHT_BIT_INTERFACE

/* #defines of the data pins and the corresponding tris pins */
/* The READ_PIN_X #defines must match the corresponding DATA_PIN_X defines */
#define DATA_PIN_7      LATBbits.LATB7
#define DATA_PIN_6      LATBbits.LATB8
#define DATA_PIN_5      LATBbits.LATB9
#define DATA_PIN_4      LATBbits.LATB10

#define READ_PIN_7		PORTBbits.RB7
#define READ_PIN_6		PORTBbits.RB8
#define READ_PIN_5		PORTBbits.RB9
#define READ_PIN_4		PORTBbits.RB10

#ifdef EIGHT_BIT_INTERFACE
#define DATA_PIN_3      LATBbits.LATB11
#define DATA_PIN_2      LATBbits.LATB12
#define DATA_PIN_1      LATBbits.LATB13
#define DATA_PIN_0      LATBbits.LATB14

#define READ_PIN_3		PORTBbits.RB11
#define READ_PIN_2		PORTBbits.RB12
#define READ_PIN_1		PORTBbits.RB13
#define READ_PIN_0		PORTBbits.RB14


#endif

#define TRIS_DATA_PIN_7       TRISBbits.TRISB7
#define TRIS_DATA_PIN_6       TRISBbits.TRISB8
#define TRIS_DATA_PIN_5       TRISBbits.TRISB9
#define TRIS_DATA_PIN_4       TRISBbits.TRISB10

#ifdef EIGHT_BIT_INTERFACE
#define TRIS_DATA_PIN_3       TRISBbits.TRISB11
#define TRIS_DATA_PIN_2       TRISBbits.TRISB12
#define TRIS_DATA_PIN_1       TRISBbits.TRISB13
#define TRIS_DATA_PIN_0       TRISBbits.TRISB14
#endif

#if defined(_RD8) && defined(_RD9) && defined(_RD10)

/* #defines of the control pins and the corresponding tris pins for 30F */
#define BL_PIN                LATBbits.LATB6       /* Backlight del LCD */
#define E_PIN                 LATBbits.LATB15      /* PORT for E */
#define RW_PIN                LATDbits.LATD14      /* PORT for RW */
#define RS_PIN                LATDbits.LATD15      /* PORT for RS */

#define TRIS_BL               TRISBbits.TRISB6    /* TRIS del BL */
#define TRIS_E                TRISBbits.TRISB15   /* TRIS for E */
#define TRIS_RW               TRISDbits.TRISD14   /* TRIS for RW */
#define TRIS_RS               TRISDbits.TRISD15   /* TRIS for RS */

#endif

/* Display ON/OFF Control defines */
#define DON                   	0x0F 	/* Display on     		*/
#define DOFF                  	0x0b 	/* Display off     		*/
#define CURSOR_ON           	0x0f  	/* Cursor on       		*/
#define CURSOR_OFF          	0x0d  	/* Cursor off      		*/
#define BLINK_ON              	0x0f  	/* Cursor Blink    		*/
#define BLINK_OFF             	0x0e  	/* Cursor No Blink 		*/

/* Some Command Type defines							*/
#define CLEAR_XLCD		0x01		/* Clears the LCD		*/
#define RETURN_CURSOR_HOME	0x02		/* Returns the cursor to the HOME position	*/


/* Entry Mode Options	*/
#define INCR_MODE		0x07		/* Increment mode		*/
#define DECR_MODE		0x05		/* Decrement Mode	*/
#define ENTIRE_SHIFT_OFF	0x06		/* Shift Entire Display 	*/
#define ENTIRE_SHIFT_ON	0x07		/* Dont Shift Entire Display	*/

/* Cursor or Display Shift defines */
#define SHIFT_CUR_LEFT        0x13  /* Cursor shifts to the left   */
#define SHIFT_CUR_RIGHT       0x17  /* Cursor shifts to the right  */
#define SHIFT_DISP_LEFT       0x1b  /* Display shifts to the left  */
#define SHIFT_DISP_RIGHT      0x1f  /* Display shifts to the right */

/* Function Set defines */
#define FOUR_BIT              0x2f  /* 4-bit Interface  */
#define EIGHT_BIT             0x3f  /* 8-bit Interface  */

/* defines for no of lines */
#define SINGLE_LINE           0x37  /* Single line display  */
#define TWO_LINE              0x3F  /* Two line display  */

/* defines for segment data transfer direction */
#define SEG1_50_SEG51_100     0x39  /* SEG1->SEG50 ,SEG51->SEG100 */
#define SEG1_50_SEG100_51     0x3d  /* SEG1->SEG50 ,SEG100->SEG51 */
#define SEG100_51_SEG50_1     0x3b  /* SEG100->SEG51,SEG50->SEG1 */
#define SEG100_51_SEG1_50     0x3f  /* SEG100->SEG51,SEG1->SEG50 */

/* defines for COM data transfer direction */

#define COM1_COM16            0x3e  /* Data transfer direction is COM1 to COM16 */

#define COM16_COM1            0x3f  /* Data transfer direction is COM16 to COM1 */

/* Function prototypes */

/* OpenXLCD
 * Configures I/O pins for external LCD
 */
void OpenXLCD(char) __attribute__ ((section (".libperi")));

/* SetCGRamAddr
 * Sets the character generator address
 */
void SetCGRamAddr(char) __attribute__ ((section (".libperi")));

/* SetDDRamAddr
 * Sets the display data address
 */
void SetDDRamAddr(char) __attribute__ ((section (".libperi")));

/* BusyXLCD
 * Returns the busy status of the LCD
 */
char BusyXLCD(void)    __attribute__ ((section (".libperi")));

/* ReadAddrXLCD
 * Reads the current address
 */
char ReadAddrXLCD(void) __attribute__ ((section (".libperi")));

/* ReadDataXLCD
 * Reads a byte of data
 */
char ReadDataXLCD(void) __attribute__ ((section (".libperi")));

/* WriteCmdXLCD
 * Writes a command to the LCD
 */
void WriteCmdXLCD(char) __attribute__ ((section (".libperi")));

/* WriteDataXLCD
 * Writes a data byte to the LCD
 */
void WriteDataXLCD(char) __attribute__ ((section (".libperi")));

/* putsXLCD
 * Writes a string of characters to the LCD
 */
void PutsXLCD(char *) __attribute__ ((section (".libperi")));

// Encender el backlight del LCD
#define BacklightOn()	BL_PIN = 1;
#define BacklightOff()	BL_PIN = 0;

#define putrsXLCD   PutsXLCD
#define getcXLCD    ReadDataXLCD
#define putcXLCD    WriteDataXLCD

/* prototypes of three delay routines used in XLCD functions */
void DelayEPulseWidth()   __attribute__ ((section (".libperi")));
void DelayPORXLCD() __attribute__ ((section (".libperi")));
void DelayXLCD()    __attribute__ ((section (".libperi")));
void Delay600nsXLCD() __attribute__((section (".libperi")));
void Delay200usXLCD(void) __attribute__((section (".libperi")));
#endif

#endif

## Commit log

2013-12-10 Added schematics, PCB design files and their printable PDF version.
    [Balsamo-cpu.sch, Balsamo-iface.sch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]
2013-12-15 - Some enhancements to user interface. - Fixed a bug playing PWM files. - Some more improvements.
    [main.c, pwmplay.c, rawplay.c]
2013-12-15 - Fixed a bug causing rawplay function to crash with an AddressException when called several times. - Added some code to ease amplifier and speaker testing. - Removed the .hex output file from the re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
    So far amplifier has been tested and works great!
    [rawplay.c]
2013-12-15 - Improved logging format, and added f_sync command to flush files before writing to log, avoiding data losses. - Fixed a bug causing that the same reply message was played for both PRIVATE and filte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
    [main.c]
2013-12-16 Finished implementation of the filter enable/disable function. It's still untested, so something might be broken!
    [main.c]
2013-12-21 - Fixed a bug locking the system when a call was received just before other ended. - Fixed allowed calls wait during RINGs. - Fixed allowed numbers printing in the LCD (it was broken in last commit).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
    [main.c]
2013-12-21 - Added PCB scans under doc directory. - Improved a bit .gitignore file.
2013-12-21 - Added PCB scans.
2013-12-22 Version number goes up to 1.0!!! Everything is working now!!! (at least everything I wanted to implement at first, and some more things). Changes: - Implemented recent call list number adding. - Fixe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
    [main.c, pwmplay.c, rawplay.c]
2013-12-22 Added a photograph of the board (BalsamoRevB.jpg)
2013-12-24 Enhanced CID errors processing, and a little bit of code cleanup.
    [main.c]
